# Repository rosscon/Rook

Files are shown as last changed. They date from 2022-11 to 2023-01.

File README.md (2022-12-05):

# Rook Modified

Welcome to my fork of the [Rook](https://github.com/rolohaun/Rook) DIY 3D Printer by [Rolohaun 3D](https://github.com/rolohaun)

There were a few tweaks I wished to make to the original project to suit my own needs and make use of some spares.

As stated in the original project, this is a small CoreXY 3D printer with a 120x120 build volume

## Original


## Modified
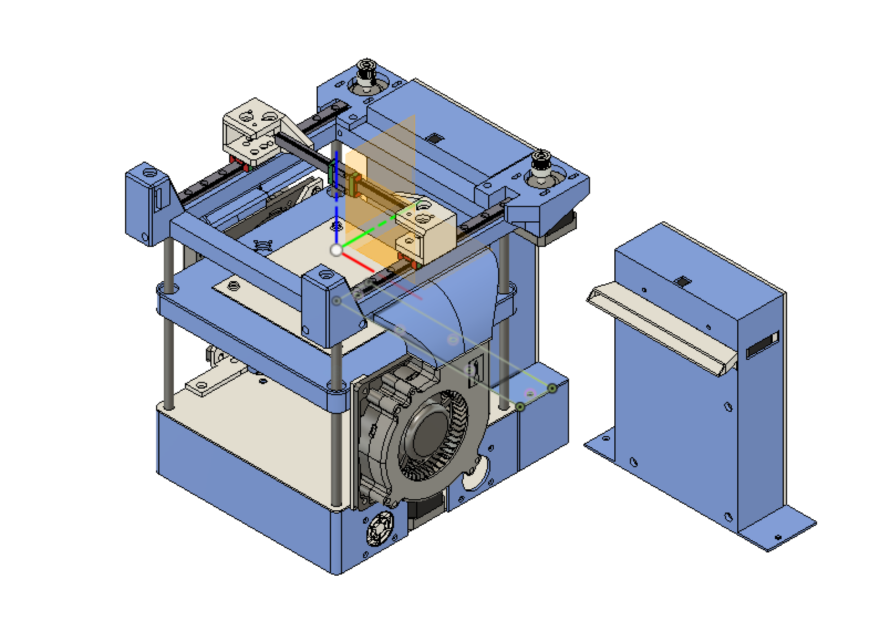
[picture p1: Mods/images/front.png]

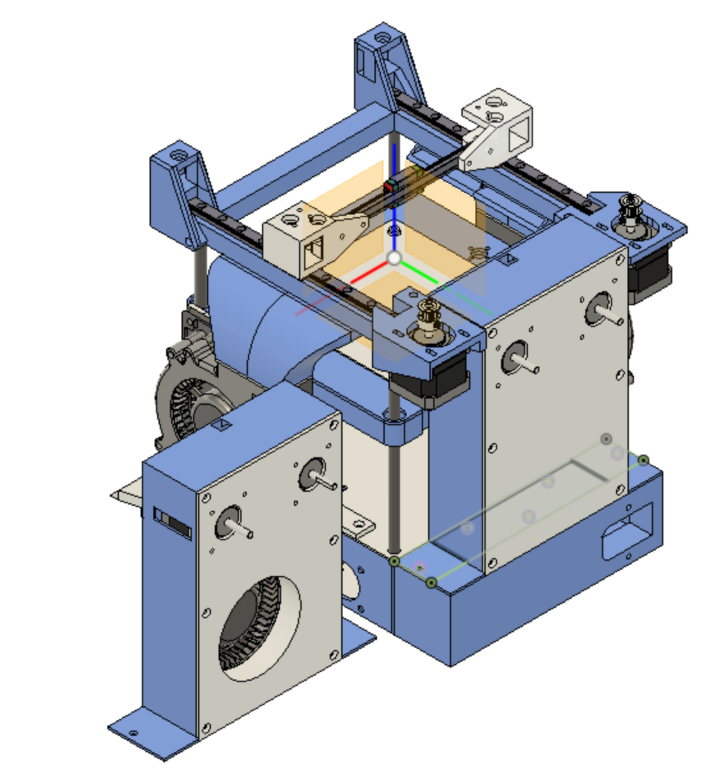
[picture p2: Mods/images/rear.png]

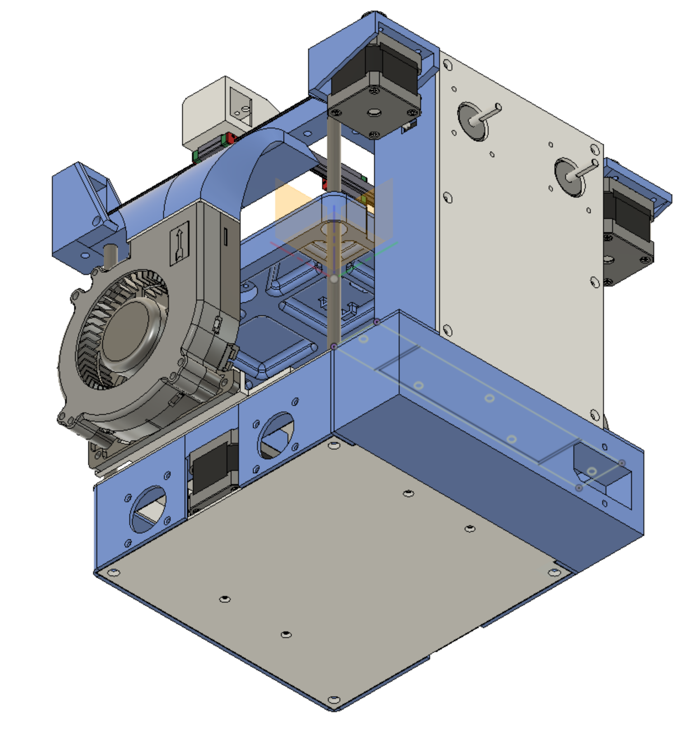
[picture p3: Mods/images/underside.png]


This is a work in progress, see below for planned modifications

For now no BOM is yet provided for this exact build, but is largely similar to the original BOM [here](https://docs.google.com/spreadsheets/d/1oHDEvndkkvPFOBis4atrHRHK_DMTvttFUFWDg2He6To/edit#gid=0)

## Modifications

I am currently still printing pars so all of these mods are currently untested!

- Enclosed frame design so electronics can be housed internally
- 120mm side blower mounts modified from lightbrigade design
- New printbed design to accomodate 120mm heated print beds from [AliExpress](https://www.aliexpress.com/item/32817223944.html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)
- Internal mounts in base for BIGTREEETECH Manta M8P board
- Internal mounts for a Meanwell LRS350 power supply
- Combined cable managment and dual extruder backbox
- IEC power connector

## Future Modifications
- Support for E3D v6 style hotends (Got a few spares lying around)
- Part cooling fan(s) on print head (removal of 120mm fan)
- Camera mounts on top frame
- RJ45 network port on rear
- WiFi Antenna Mounting

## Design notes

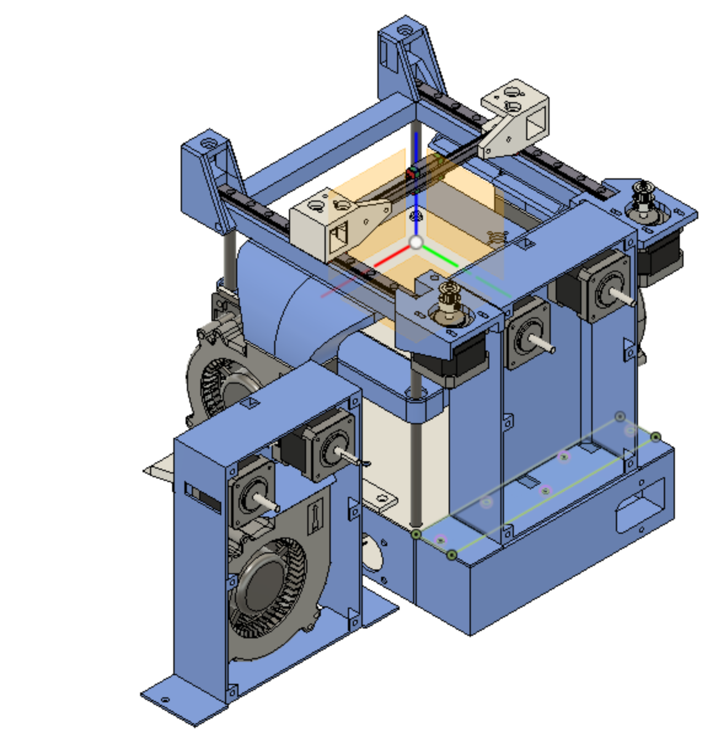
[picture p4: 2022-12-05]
Mods/images/rear_no_lid.png

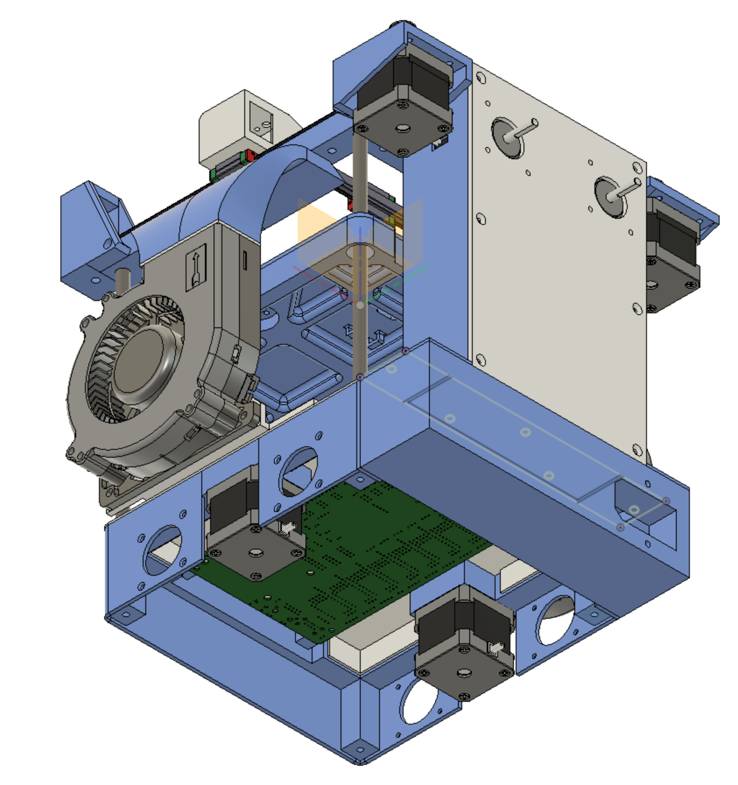
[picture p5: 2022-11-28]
Mods/images/underside_no_cover_no_psu.png

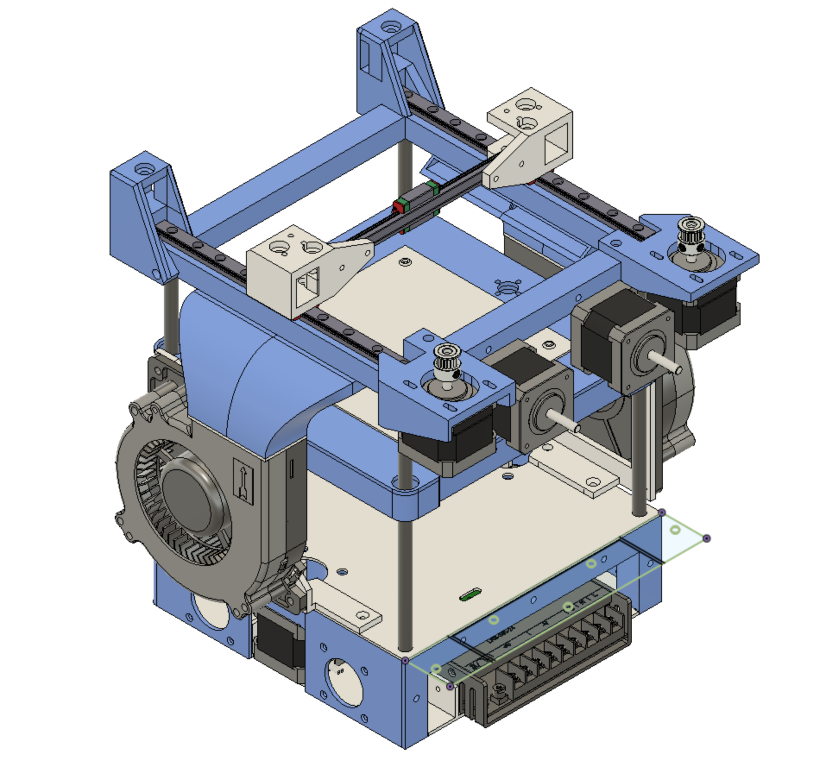
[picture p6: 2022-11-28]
Mods/images/rear_no_back.png

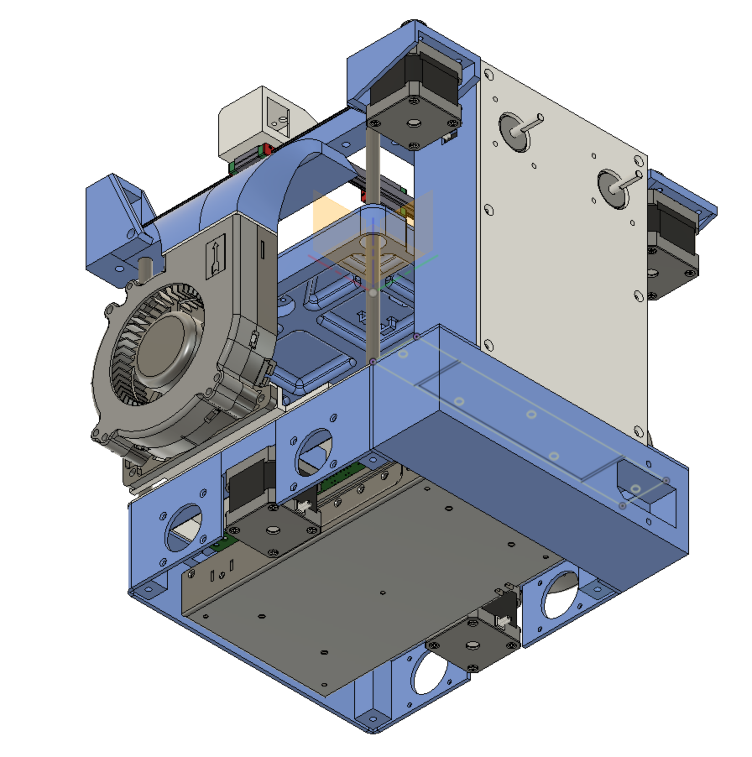
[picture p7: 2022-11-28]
Mods/images/underside_no_cover.png

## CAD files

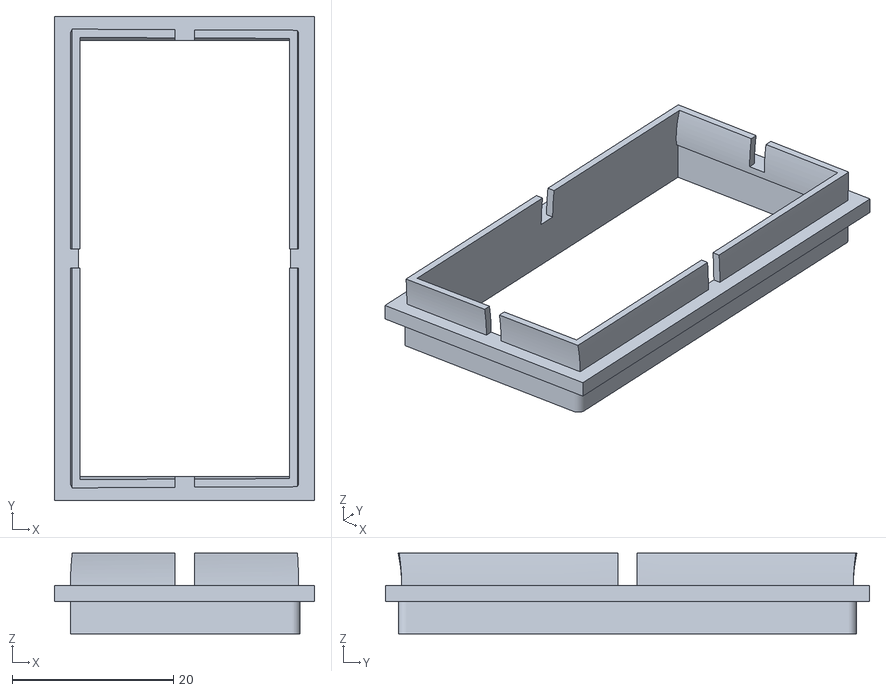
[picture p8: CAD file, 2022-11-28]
Mods/Fan Bracket/Fan Duct Coupler.stl
32.3 x 60.0 x 10.0

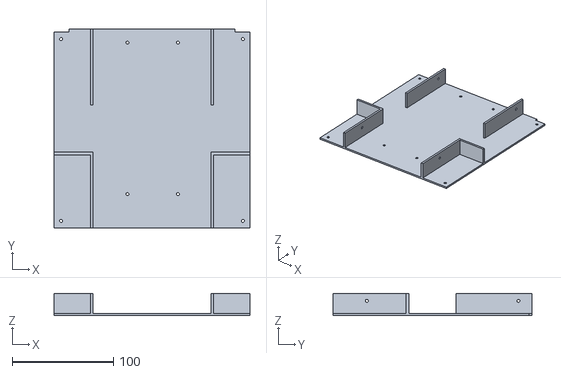
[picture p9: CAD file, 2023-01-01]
Mods/Frame/BottomCover.stl
194.0 x 197.0 x 22.0

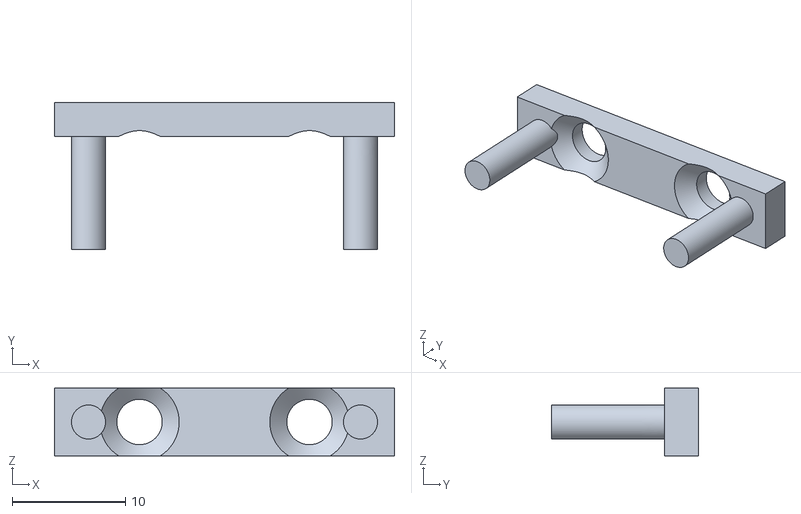
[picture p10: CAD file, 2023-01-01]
Mods/Hotend/Front_fan.stl
30.0 x 13.0 x 6.00

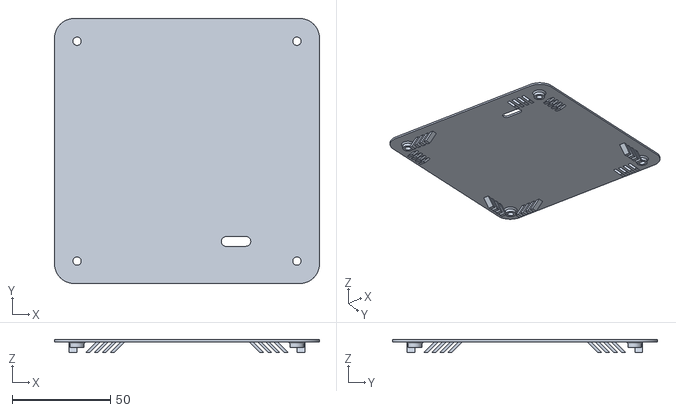
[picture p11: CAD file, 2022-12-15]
Mods/PrintBed/BedHeatShield.stl
135.0 x 135.0 x 6.70

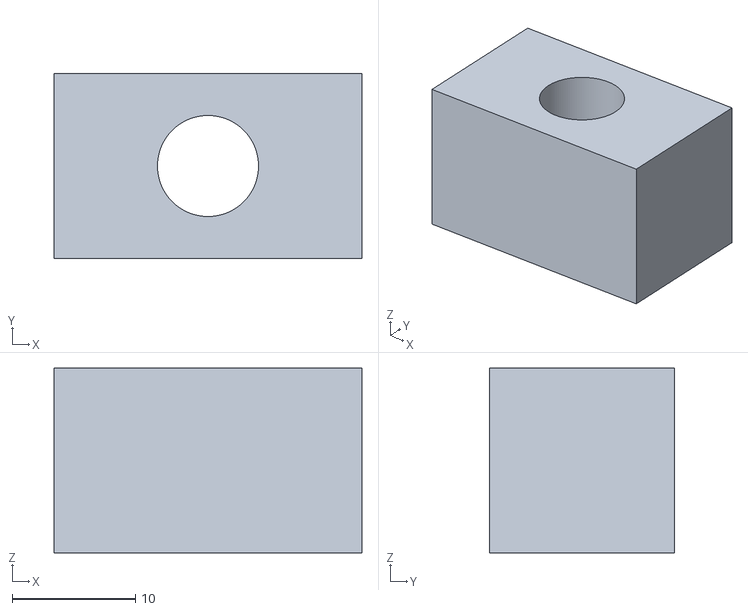
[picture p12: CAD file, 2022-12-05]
STLs/Calibration Tools/8mm_Z_Rod_Tolerance_Check.stl
25.0 x 15.0 x 15.0

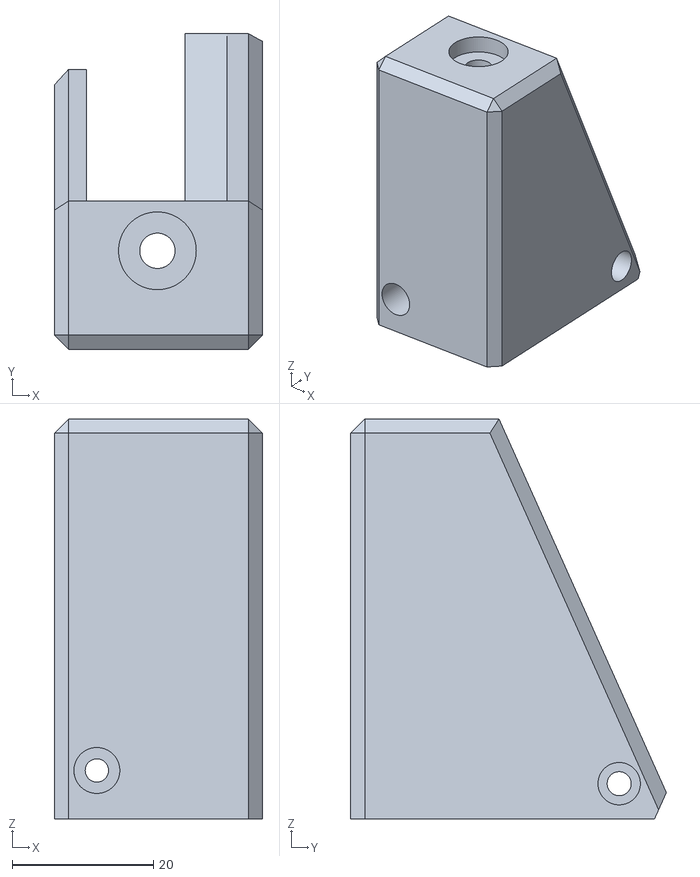
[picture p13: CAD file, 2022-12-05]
STLs/Frame/Right_Idler_v1_easier_to_print.stl
29.4 x 44.7 x 56.6

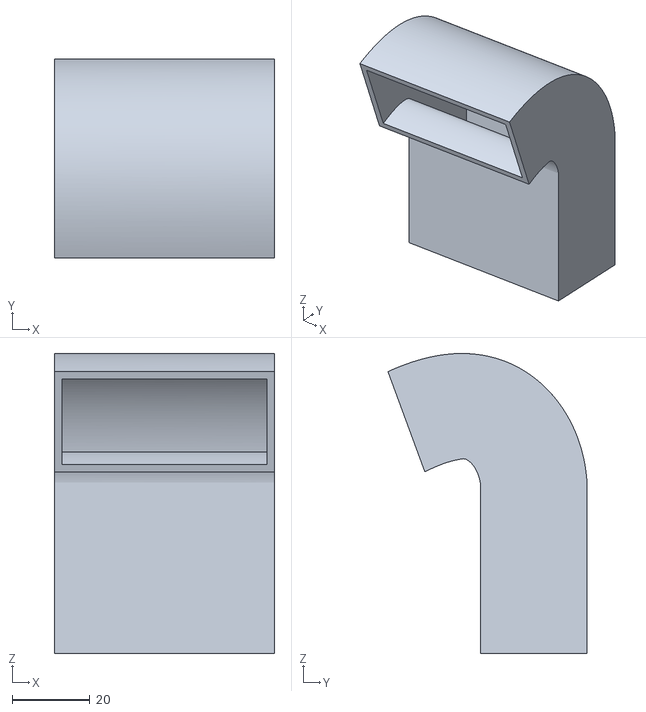
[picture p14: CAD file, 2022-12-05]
STLs/Layer Cooling/120mm_duct.stl
56.8 x 51.2 x 77.2

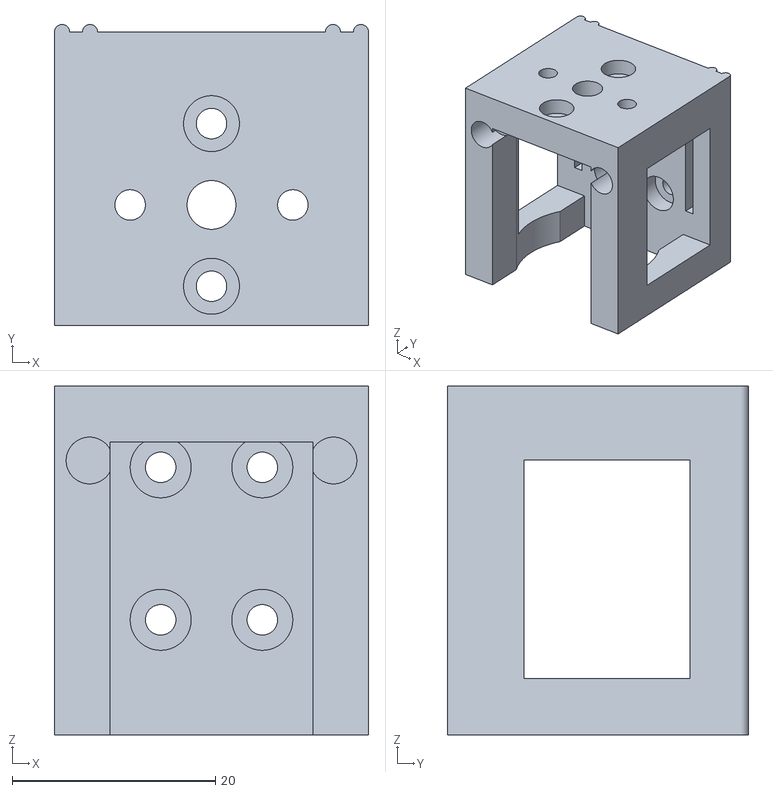
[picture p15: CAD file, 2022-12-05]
STLs/X_Carriage_TL_CHC_TD6S.stl
30.9 x 29.6 x 34.3

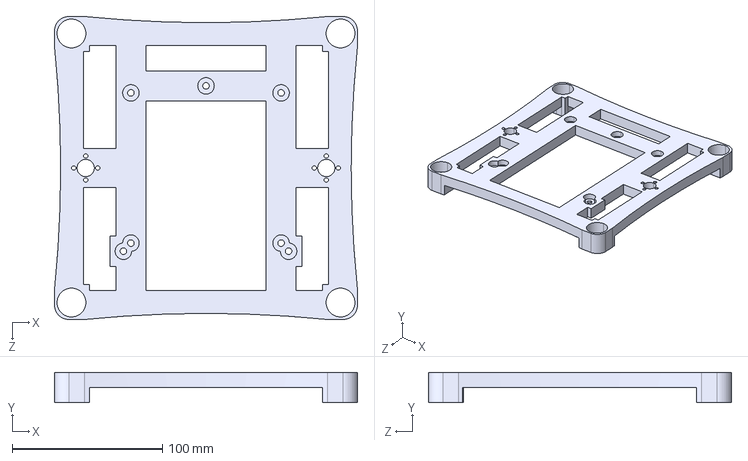
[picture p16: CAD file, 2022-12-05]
User_Mods/Mods by Gulsifer/10mm_Z_Rods/CAD/V1Rook_Tray_10mm_2.1.STEP
201.7 x 20.0 x 201.7 mm

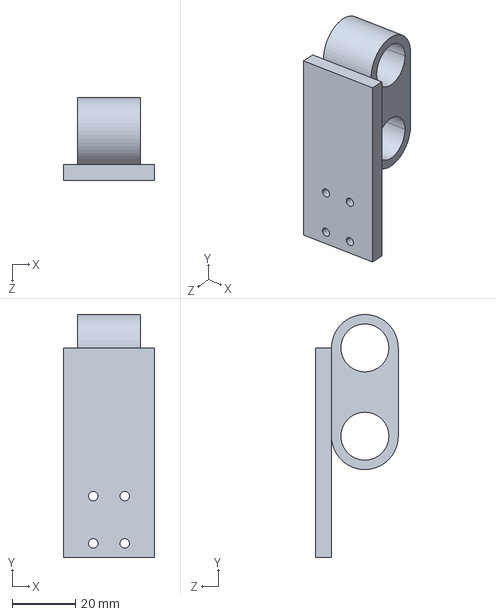
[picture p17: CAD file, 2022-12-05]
User_Mods/Mods by Gulsifer/Rook_Rod_All_linear_Rod_version/CAD/V1 Head Mount ROD MOD.STEP
29.0 x 77.1 x 26.2 mm

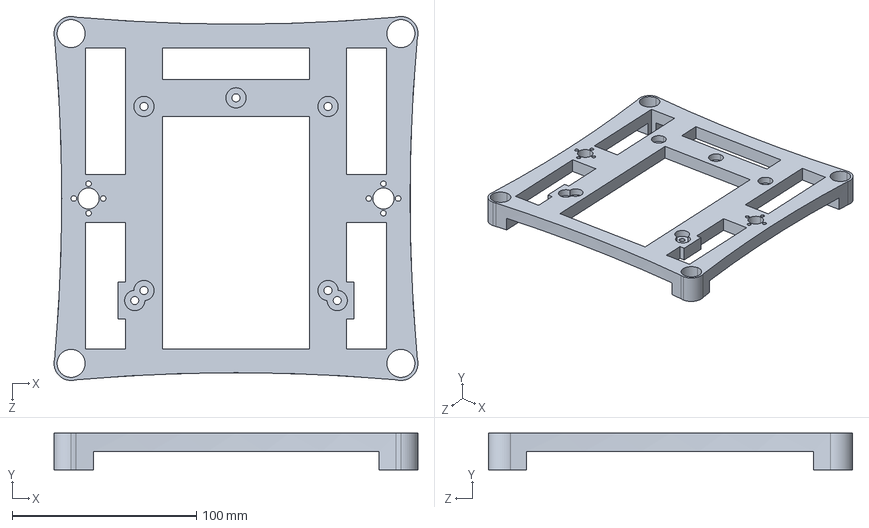
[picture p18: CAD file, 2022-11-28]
User_Mods/Mods by Gulsifer/Stock_8mm_Z_Rods/CAD/V1Rook_Tray_2.0.STEP
197.7 x 20.0 x 197.7 mm

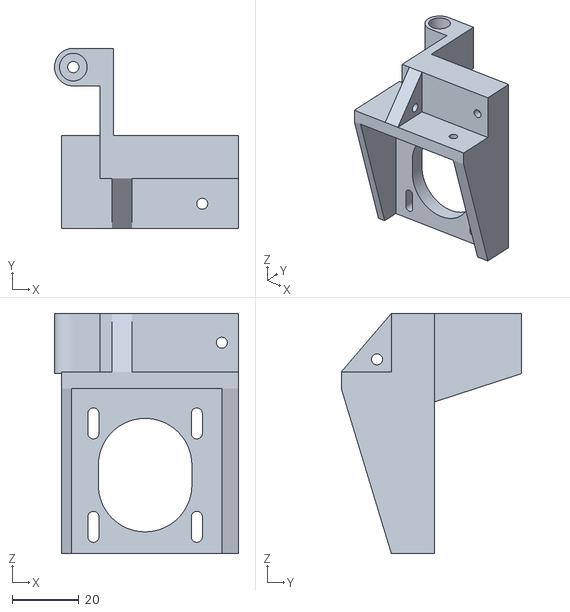
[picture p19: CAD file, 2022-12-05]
User_Mods/Mods by Leviathan3DPrinting/Ender 3 v2 motor mounts/STLs/X_MOTOR.stl
55.2 x 54.1 x 71.9

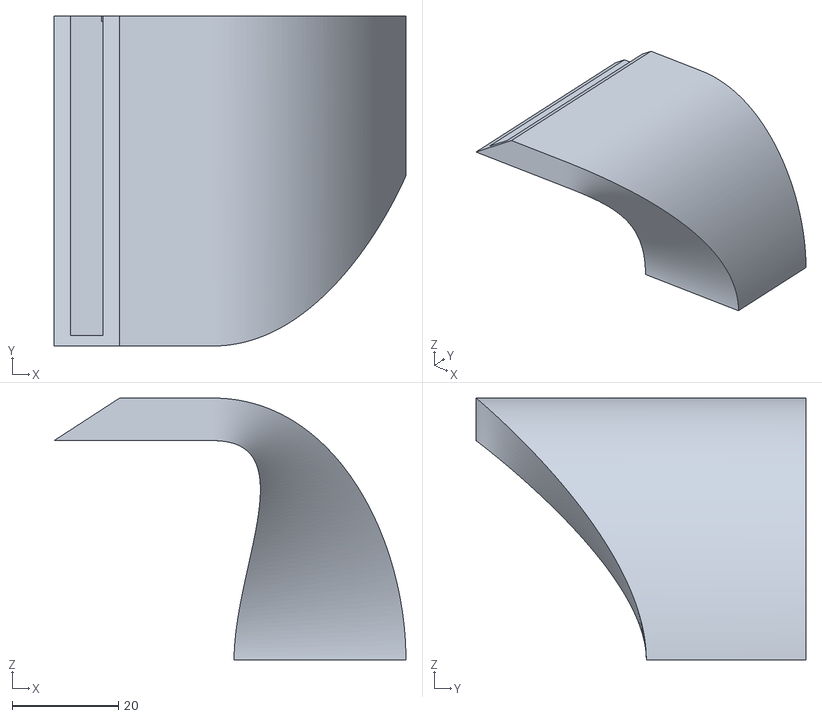
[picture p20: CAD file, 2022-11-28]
Mods/Fan Bracket/Duct Supported.stl
66.1 x 62.0 x 49.2

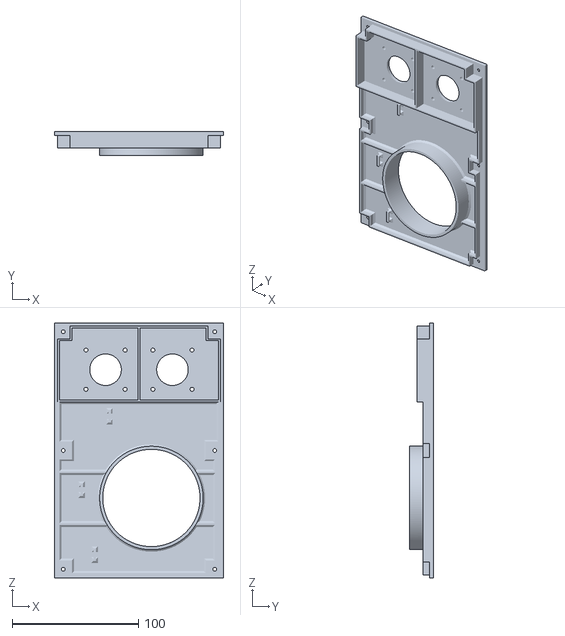
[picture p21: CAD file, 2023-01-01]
Mods/Frame/backboxlid_fan.stl
134.0 x 18.7 x 202.0

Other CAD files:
STLs/Gantry/Left_Idler_v2__polished_MK1.stl
Mods/Hotend/MGN9C_HotendMount.stl
Mods/PrintBed/PrintBedFrame.stl
STLs/Frame/Right_Idler_v2__polished_with_overhangs.stl
Mods/Fan Bracket/FanBracket.stl
Mods/Frame/Bottom_Frame.stl
Mods/Frame/Bottom_Frame_pnl_fan_fl.stl
Mods/Frame/Bottom_Frame_pnl_fan_fr.stl
Mods/Frame/Bottom_Frame_pnl_fan_rl.stl
Mods/Frame/Bottom_Frame_pnl_fan_rr.stl
Mods/Frame/Bottom_Frame_pnl_front.stl
Mods/Frame/Bottom_Frame_topper.stl
Mods/Frame/Endstop mount.stl
Mods/Frame/Fan Grill 40mm.stl
Mods/Frame/PSU_Safety Cover.stl
Mods/Frame/Right_Motor_Mount.stl
Mods/Frame/Top_Frame.stl
Mods/Frame/backbase.stl
Mods/Frame/backbox.stl
Mods/Frame/backbox_fan.stl
Mods/Frame/backboxlid.stl
Mods/Frame/exo_backbox.stl
Mods/Frame/exo_backboxlid.stl
Mods/Frame/vent.stl
Mods/PrintBed/PrintBedTop.stl
STLs/Bed_Pad_for_springs.stl
STLs/Frame/Bed_Frame.stl
STLs/Frame/Bed_Frame_v2.stl
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

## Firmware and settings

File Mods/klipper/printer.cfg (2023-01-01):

[include mainsail.cfg]

[mcu]
serial: /dev/serial/by-id/usb-Klipper_stm32g0b1xx_3D000B0012504B4633373520-if00
restart_method: command

[temperature_sensor MCU]
sensor_type: temperature_mcu

[temperature_sensor SoC]
sensor_type: temperature_host


[printer]
kinematics: corexy
max_velocity: 300  
max_accel: 30000    			#Max 3000
max_z_velocity: 25 			    #Max 15 for 12V TMC Drivers, can increase for 24V
max_z_accel: 350
square_corner_velocity: 5.0


[stepper_x]
step_pin: PE2
dir_pin: PB4
enable_pin: !PC11
microsteps: 16
rotation_distance: 40
endstop_pin: tmc2209_stepper_x:virtual_endstop
position_endstop: 0
position_max: 235
homing_speed: 50

[tmc2209 stepper_x]
uart_pin: PC10
diag_pin: ^PF3
driver_SGTHRS: 64  # 255 is most sensitive value, 0 is least sensitive
interpolate: true
run_current: 0.8
hold_current: 0.3
sense_resistor: 0.110
stealthchop_threshold: 0

[stepper_y]
step_pin: PF12
dir_pin: PF11
enable_pin: !PB3
microsteps: 16
rotation_distance: 40
endstop_pin: tmc2209_stepper_y:virtual_endstop
position_endstop: 0
position_max: 235
homing_speed: 50


[tmc2209 stepper_y]
uart_pin: PF13
diag_pin: ^PF4
driver_SGTHRS: 64  # 255 is most sensitive value, 0 is least sensitive
interpolate: true
run_current: 0.8
hold_current: 0.3
sense_resistor: 0.110
stealthchop_threshold: 0



# right
[stepper_z]
step_pin: PD7
dir_pin: PD6
enable_pin: !PF10
rotation_distance: 40
gear_ratio: 80:16
microsteps: 16
endstop_pin: tmc2209_stepper_z:virtual_endstop
position_endstop: 100
position_max: 150
position_min: -5
homing_speed: 8
homing_retract_dist: 0
homing_positive_dir: true

##	Make sure to update below for your relevant driver (2208 or 2209)
[tmc2209 stepper_z]
uart_pin: PF9
diag_pin: ^PF5
driver_SGTHRS: 64  # 255 is most sensitive value, 0 is least sensitive
interpolate: true
run_current: 0.8
hold_current: 0.3
sense_resistor: 0.110
stealthchop_threshold: 0


[stepper_z1]
step_pin: PD3
dir_pin: PD2
enable_pin: !PD5
rotation_distance: 40
gear_ratio: 80:16
microsteps: 16
endstop_pin: tmc2209_stepper_z:virtual_endstop


##	Make sure to update below for your relevant driver (2208 or 2209)
[tmc2209 stepper_z1]
uart_pin: PD4
diag_pin: ^PC0
driver_SGTHRS: 64  # 255 is most sensitive value, 0 is least sensitive
interpolate: true
run_current: 0.8
hold_current: 0.8
sense_resistor: 0.110
stealthchop_threshold: 0


[heater_bed]
heater_pin: PB7
sensor_pin: PA0 # TB
sensor_type: EPCOS 100K B57560G104F
#control: pid
#pid_kp = 69.108
#pid_ki = 2.916
#pid_kd = 409.465
min_temp: 0
max_temp: 90


[extruder]
step_pin: PC9
dir_pin: !PC8
enable_pin: !PD1
microsteps: 16
rotation_distance: 7.8624078624
full_steps_per_rotation: 200
nozzle_diameter: 0.4
filament_diameter: 1.75
heater_pin: PE3 # HE0
sensor_pin: PA1 # T0
sensor_type: EPCOS 100K B57560G104F
control: pid
pid_kp: 26.213
pid_ki: 1.304
pid_kd: 131.721
min_temp: 0
max_temp: 250
min_extrude_temp: 15
max_extrude_only_distance: 200

[tmc2209 extruder]
uart_pin: PD0
interpolate: true
run_current: 0.8
hold_current: 0.3
sense_resistor: 0.110
stealthchop_threshold: 0


# Driver4 (Extruder 2 / T1)
[extruder_stepper extruder1]
extruder: 
step_pin: PA10
dir_pin: PD15
enable_pin: !PA15
microsteps: 16
rotation_distance: 7.8624078624
full_steps_per_rotation: 200

[tmc2209 extruder_stepper extruder1]
uart_pin: PF8
interpolate: true
run_current: 0.8
hold_current: 0.3
sense_resistor: 0.110
stealthchop_threshold: 0


[gcode_macro CHANGE_TOOL]
variable_selected_tool: "T0"
gcode:

  {% set tool = params.TOOL|default("T0")|string %}

  M118 Changing tool to {tool}

  # If toolchange remove currrent filament from nozzle
  {% if tool != selected_tool %}
    M118 Unload current filament ({selected_tool}) from nozzle
    UNLOAD_FROM_NOZZLE_TO_SPLITTER
  {% endif %}


  # Set new stepper motor config


  {% if tool == 'T0' %}
    SYNC_EXTRUDER_MOTION EXTRUDER="extruder" MOTION_QUEUE="extruder"
    SYNC_EXTRUDER_MOTION EXTRUDER="extruder1" MOTION_QUEUE=""
    SET_STEPPER_ENABLE STEPPER="extruder_stepper extruder1" ENABLE=0
  {% elif tool == 'T1' %}
    SYNC_EXTRUDER_MOTION EXTRUDER="extruder" MOTION_QUEUE=""
    SYNC_EXTRUDER_MOTION EXTRUDER="extruder1" MOTION_QUEUE="extruder"    
    SET_STEPPER_ENABLE STEPPER="extruder" ENABLE=0
  {% else %}
    M118 Invaid Tool {tool}
  {% endif %}

  # If toolchange load new filament
  {% if tool != selected_tool %}
    M118 Load new filament ({tool}) to nozzle
    LOAD_FROM_SPLITTER_TO_NOZZLE
  {% endif %}

  # Finally acknowledge toolchange and set vaiable to new tool
  M118 Set Tool
  SET_GCODE_VARIABLE MACRO=CHANGE_TOOL VARIABLE=selected_tool VALUE='"{tool}"'
  M118 Done Set Tool

[gcode_macro T0]
gcode:
    CHANGE_TOOL TOOL="T0"

[gcode_macro T1]
gcode:    
    CHANGE_TOOL TOOL="T1"


[gcode_macro UNLOAD_FROM_NOZZLE_TO_SPLITTER]
gcode:
  G92 E0
  # Fast Yank
  G1 E-10 F2000
  G92 E0
  G1 E-90 F1000


[gcode_macro LOAD_FROM_SPLITTER_TO_NOZZLE]
gcode:
  G92 E0
  # Fast Start
  G1 E80 F1200

  G92 E0
  G1 E10 F800

  # Slow last part, allow time for filamant to warm up
  G92 E0
  G1 E10 F200



[respond]
default_type: echo
default_prefix: 

[fan]
pin: PE6

[heater_fan fan1]
pin: PE0

[temperature_fan MCU_CB1_fan]
pin: PC12
sensor_type: temperature_host
control: watermark
min_temp: 0
max_temp: 85
min_speed: 0.8
max_speed: 1
target_temp: 45

[controller_fan Controllers_fan]
pin: PE5
stepper: extruder,stepper_z,stepper_y,stepper_x


[board_pins]
aliases:
    # EXP1 header
    EXP1_1=PE9, EXP1_2=PE10,
    EXP1_3=PE11, EXP1_4=PE12,
    EXP1_5=PE13, EXP1_6=PE14,    # Slot in the socket on this side
    EXP1_7=PE15, EXP1_8=PB10,
    EXP1_9=<GND>, EXP1_10=<5V>,

    # EXP2 header
    EXP2_1=PB14, EXP2_2=PB13,
    EXP2_3=PF7, EXP2_4=PB12,
    EXP2_5=PE7, EXP2_6=PB11,      # Slot in the socket on this side
    EXP2_7=PE8, EXP2_8=<RST>,
    EXP2_9=<GND>, EXP2_10=PC5

#*# <---------------------- SAVE_CONFIG ---------------------->
#*# DO NOT EDIT THIS BLOCK OR BELOW. The contents are auto-generated.
#*#
#*# [heater_bed]
#*# control = pid
#*# pid_kp = 69.108
#*# pid_ki = 2.916
#*# pid_kd = 409.465

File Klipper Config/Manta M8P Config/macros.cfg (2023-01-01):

[gcode_macro START_PRINT]
variable_purge: 1
gcode:
    {% set bed_temp = params.BED_TEMP|float %}
    {% set extruder_temp = params.EXTRUDER_TEMP|float %}

    {% set tool = params.TOOL|default(-1)|int %}

    G21                                          ; Metric values
    G90                                          ; Absolute positioning
    M82                                          ; Set extruder to absolute mode
    M140 S{bed_temp}                             ; Start heating the bed
    M104 S{extruder_temp - 60}                   ; start heating the hot end
    
    M190 S{bed_temp}                             ; Wait for bed

    SET_VELOCITY_LIMIT VELOCITY=150 ACCEL=2500 ACCEL_TO_DECEL=1750 SQUARE_CORNER_VELOCITY=5
    G28                                         ; Home XYZ

    M109 S{extruder_temp}                       ; Wait for hotend

    {% if tool != -1 %}
      T{tool}
    {% else %}
      LOAD_FROM_SPLITTER_TO_NOZZLE
    {% endif %}

    {% if purge == 1 %}
        G0 X0 Y0 Z0.2 F1500
        G92 E0                                   ; Zero the extruded length
        G1 X100 E20 F500                         ; Extrude 50mm of filament in a line.
        G92 E0                                   ; Zero the extruded length again
        G1 X120 Y0 F4000                         ; Quickly wipe away from the filament line
        M83                                      ; extruder relative mode
    {% else %}
        G1 E15 F500
        M300 S299 P200
        M300 S299 P200
        M300 S299 P200
        G4 P5000
        G92 E0
        M83
    {% endif %}

[gcode_macro END_PRINT]
variable_shutdown: 0
variable_nonstop: 0
gcode:

    G90  # Absolute Positionining

    # Move bed down nd head out of the way
    G0 X{printer.toolhead.axis_maximum.x-10} Y{printer.toolhead.axis_maximum.y-10} Z{printer.toolhead.axis_maximum.z} F{50*60}

    UNLOAD_FROM_NOZZLE_TO_SPLITTER

    M107                                          ; Fan off
    M300 S299 P200
    M300 S299 P200
    M300 S299 P200
    M300 S299 P200
    M300 S299 P200
    {% if nonstop == 0 %}
        M84                                       ; Disable stepper motors
        BED_MESH_CLEAR
        TURN_OFF_HEATERS
    {% else %}
        M300 S299 P200
        M300 S299 P200
        M300 S299 P200
        M300 S299 P200
    {% endif %}

[gcode_macro CANCEL_PRINT]
rename_existing: BASE_CANCEL_PRINT
gcode:
    # Reset Speed factor override percentage to default (100%)
    M220 S100
    # Reset Extrude factor override percentage to default (100%)
    M221 S100
    END_PRINT
    TURN_OFF_HEATERS
    CLEAR_PAUSE
    SDCARD_RESET_FILE
    BASE_CANCEL_PRINT



[gcode_macro CHANGE_TOOL]
variable_selected_tool: "T?"
gcode:

  {% set tool = params.TOOL|default("T0")|string %}

  M118 Changing tool to {tool}

  # If toolchange remove currrent filament from nozzle
  {% if selected_tool != 'T?' %}
    {% if tool != selected_tool %}
      M118 Unload current filament ({selected_tool}) from nozzle
      UNLOAD_FROM_NOZZLE_TO_SPLITTER
    {% endif %}
  {% endif %}

  # Set new stepper motor config


  {% if tool == 'T0' %}
    SYNC_EXTRUDER_MOTION EXTRUDER="extruder" MOTION_QUEUE="extruder"
    SYNC_EXTRUDER_MOTION EXTRUDER="extruder1" MOTION_QUEUE=""
    SET_STEPPER_ENABLE STEPPER="extruder_stepper extruder1" ENABLE=0
  {% elif tool == 'T1' %}
    SYNC_EXTRUDER_MOTION EXTRUDER="extruder" MOTION_QUEUE=""
    SYNC_EXTRUDER_MOTION EXTRUDER="extruder1" MOTION_QUEUE="extruder"    
    SET_STEPPER_ENABLE STEPPER="extruder" ENABLE=0
  {% else %}
    M118 Invaid Tool {tool}
  {% endif %}

  # If toolchange load new filament
  {% if tool != selected_tool %}
    M118 Load new filament ({tool}) to nozzle
    LOAD_FROM_SPLITTER_TO_NOZZLE
  {% endif %}

  # Finally acknowledge toolchange and set vaiable to new tool
  M118 Set Tool
  SET_GCODE_VARIABLE MACRO=CHANGE_TOOL VARIABLE=selected_tool VALUE='"{tool}"'
  M118 Done Set Tool

[gcode_macro T0]
gcode:
    CHANGE_TOOL TOOL="T0"

[gcode_macro T1]
gcode:    
    CHANGE_TOOL TOOL="T1"


[gcode_macro UNLOAD_FROM_NOZZLE_TO_SPLITTER]
gcode:
  G92 E0
  # Fast Yank
  G1 E-10 F2000
  G92 E0
  G1 E-90 F1000


[gcode_macro LOAD_FROM_SPLITTER_TO_NOZZLE]
gcode:
  G92 E0
  # Fast Start
  G1 E80 F1200

  G92 E0
  G1 E10 F800

  # Slow last part, allow time for filamant to warm up
  G92 E0
  G1 E10 F200

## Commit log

2022-11-18 Added new bed frame
    [Rook Bed Frame v2.f3d, Rook Bed Frame v2.stl]
2022-11-20 updated CAD files and images
    [BottomCover.stl, Bottom_Frame.stl, FanBracket.stl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]
2022-11-21 updated bottom cover
    [BottomCover.stl]
2022-11-21 add IEC power connector
    [backbase.stl, backbox lid.stl, backbox.stl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]
2022-11-21 backbox lid strengthen
    [backboxlid.stl]
2022-11-28 Part cooling mods, bottom frame modular, print bed changes
    [BedHeatShield.stl, Bottom_Frame.stl, Bottom_Frame_pnl_fan_fl.stl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]
2022-12-05 Added backbox cooling fan
    [BedHeatShield.stl, Fan Grill 40mm.stl, backbox_fan.stl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]
2022-12-08 adjust extruder positions
    [backboxlid.stl, backboxlid_fan.stl]
2022-12-12 Adjusted mainboard mounting, added PSU safety cover
    [Bottom_Frame.stl, Bottom_Frame_topper.stl, PSU_Safety Cover.stl]
2022-12-15 initial printer config
    [BedHeatShield.stl, printer.cfg]
2023-01-01 Working printer
    [BottomCover.stl, Endstop mount.stl, Fan Grill 40mm.stl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]
2023-01-01 add initial klipper config
    [macros.cfg, printer.cfg, sensorless.cfg]
